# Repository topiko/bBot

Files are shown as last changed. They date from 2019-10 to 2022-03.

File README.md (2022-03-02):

### Robert is a much cabable balancing robot!

Check the notes of how to make it balance in control.pdf (also the Kalman filter math) and in practice in Raspberry/balance_run.py

[Video link](https://www.youtube.com/watch?v=8lWUVSnFbXg)

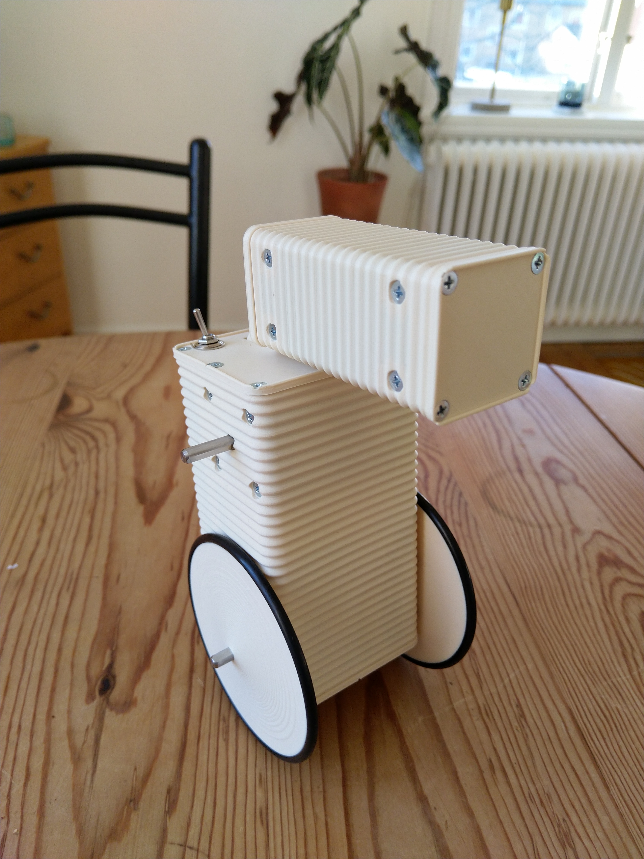
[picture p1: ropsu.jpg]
Robert (https://www.youtube.com/watch?v=8lWUVSnFbXg)


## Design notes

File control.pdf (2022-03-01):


Figure 1: Ropsu looks good and has wheels and head

# How to make Ropsu Balance

Topsu | 20/05/2020

# 1 Overview

You need to keep Ropsu upright. Ropsu is very unstable!

You can only acces the wheel angular velocity, under no slip this means velocity of Ropsus

hip.

Lagrange of Ropsu reads (See. A):

## L = −F x(t) + J

2

d

## dtθ(t)

2

## − Lcmgm cos (θ(t)) + Lcmm cos (θ(t)) d dtθ(t)

d

## dtx(t) + m

2

d

## dtx(t)

2

(1)

From which we yield Eqs. of motion:

## F − Lcmm sin (θ(t))

d

## dtθ(t)

2

## + Lcmm cos (θ(t)) d

2

## dt²

## θ(t) + m

d

2

## dt²

x(t) = 0 | (2)

J

d

2

## dt²

## θ(t) − Lcmgm sin (θ(t)) + Lcmm cos (θ(t)) d

2

## dt²

x(t) = 0 | (3)

Using 3 we get:

d

2

## dt²

θ =

## Lcmm

J

## g sin (θ(t)) − cos (θ(t)) d

2

## dt²

x(t)

(4)

a = −

J

d

2
dt² θ(t)
Lcmm cos (θ(t)) + g tan (θ(t)) | (5)

Equipped with Eq. 4 we can see how to apply a in each situation θ to achieve given d

2
dt² θ. Control

is then based in deciding desired d

2
dt² θ using Eq. 4 get a.

# 2 Model Fit

We always record a, θ, d

2
dt² θ so using Eq. 4 we can fit a model and obtain the factor Lcmm J

. This

is further fed to the Kalman filter.

# 3 Control

We use PID to get:
d

2

## dt²

## θ = P∆θ + I

Z

## ∆θdt + D

d
dt∆θ, | (6)
where ∆θ is the difference from targeted θ. | Note that using I = 0 this is damped harmonic

oscillator.

# 3.1 Issue

We get particularly crappy and noisy values for the d

2
dt² θ (see Fig. 2). I suppose also the values

d
dtθ are messed and hence the obtained values a become also very noisy. This leads to all sorts

of issues. <++>

# 4 Hardware

We use RaspberryPi Zero and an arduino due communicating via serila connection. Arduino

takes care of readin values from IMU (inertial measurement unit) and controlling the wheels/-

head/hands (as of now only wheels and head). We use stepper motors to have precise control

over the position. Raspberry is used to take care of all control logic since I am not very com-

fortable with c++. Moreover I can easily ssh into the Raspberry and do the development without

need to flash the program into arduino etc..

# A Lagrange

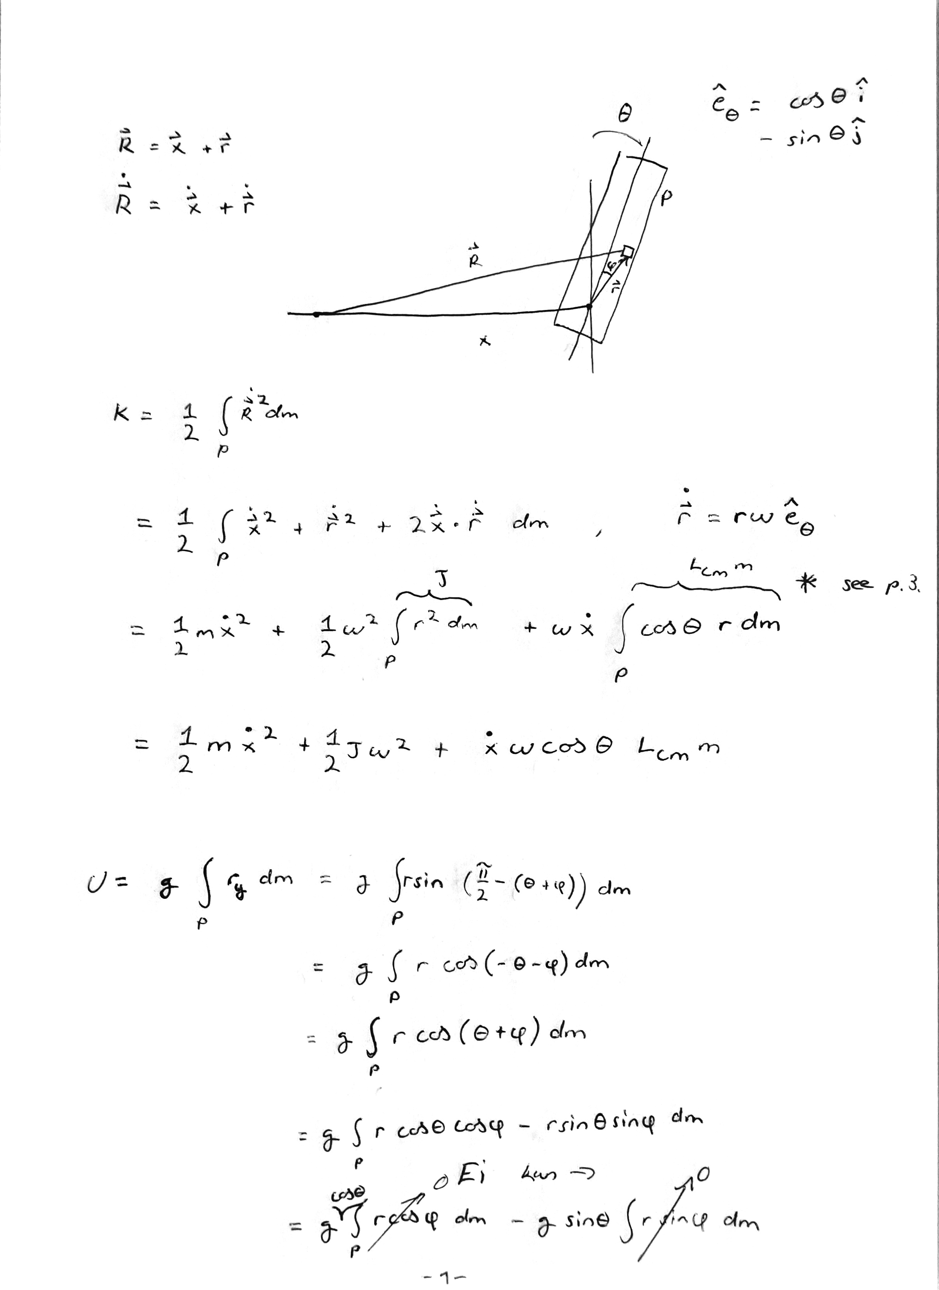
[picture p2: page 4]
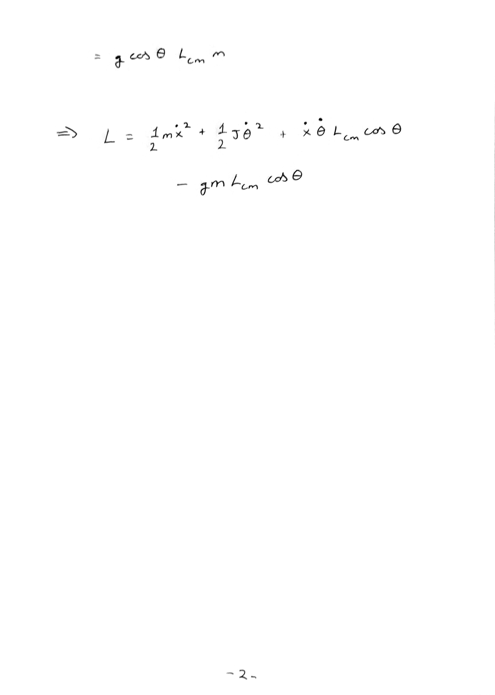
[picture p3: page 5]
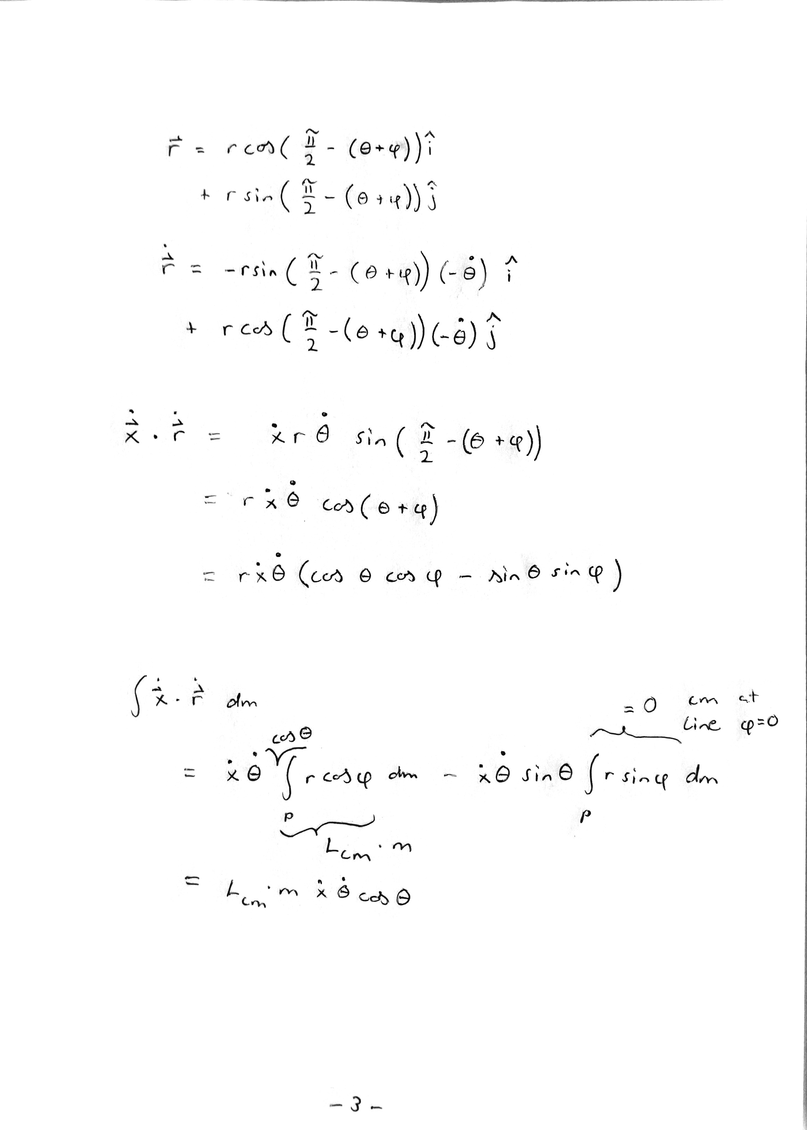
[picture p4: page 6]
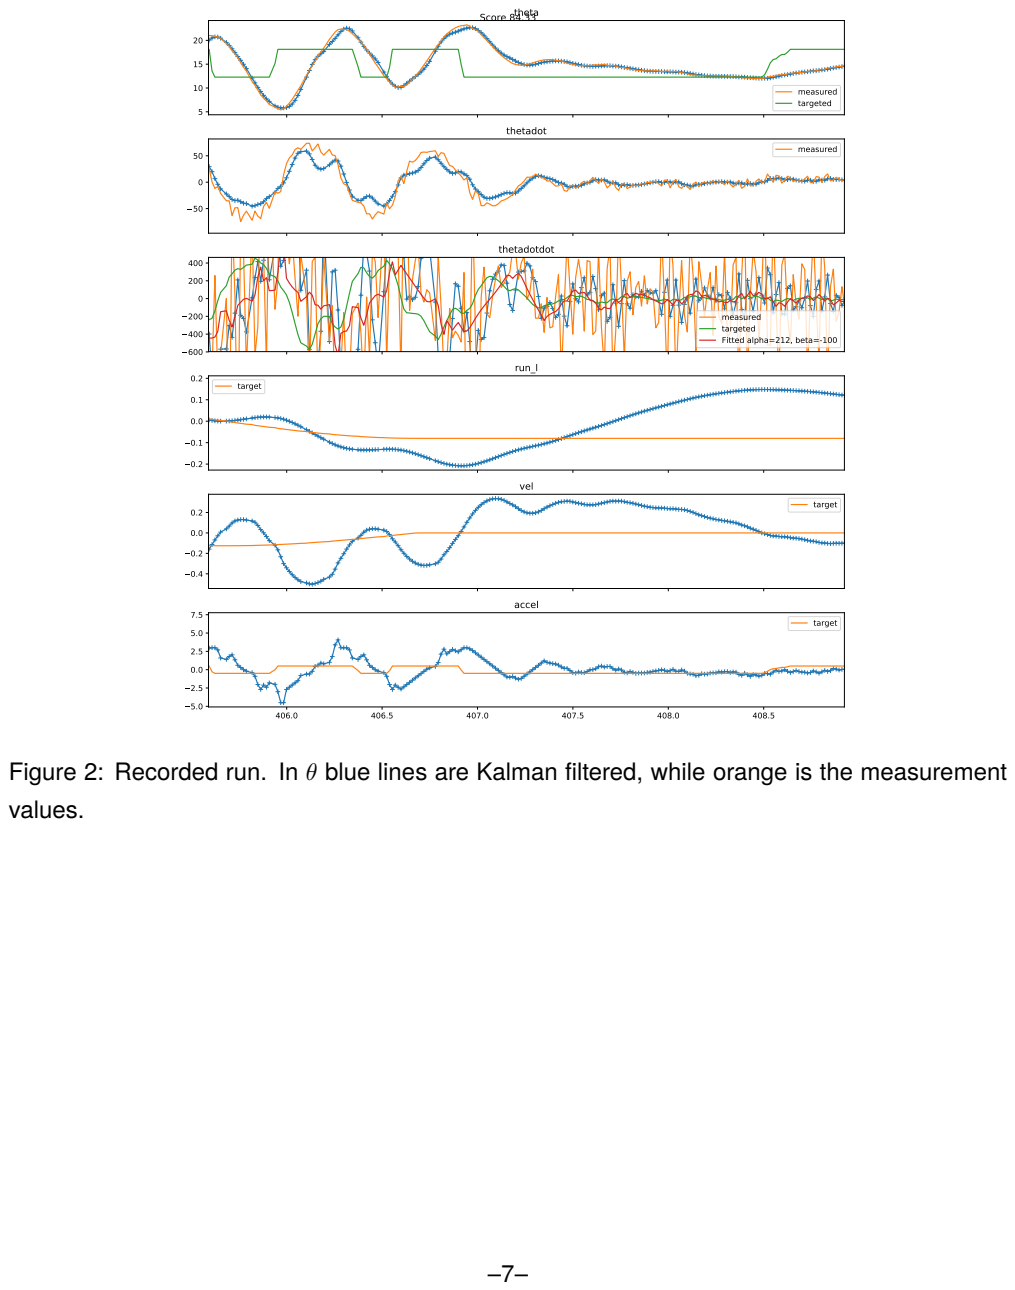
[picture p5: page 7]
theta; measured targeted; thetadot; measured; thetadotdot; run_l; target; vel; accel; Score 84.33; values.

measured
targeted
Fitted alpha=212, beta=-100

Figure 2: Recorded run. In θ blue lines are Kalman filtered, while orange is the measurement

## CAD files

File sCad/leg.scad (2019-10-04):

include <design.scad>;
use <nema14.scad>;
use <wigleUnit.scad>;
use <wheel.scad>;


module noLeg(wx, wy, r_corner, sc, sc2, mid, A_out, ni, t, t_motor_mount, wall_t, axle_x, bolt_sink, motors, a){

    
    axle_h = t + nema14_x/2;
    
    // LEG:    
    module motor_and_wheel_(){
        // MOTOR MOUNTS
        translate([axle_x, -nema14_z + wy/2 - t_motor_mount + A_out, axle_h])   rotate([-90,0,0])
        union(){
        if (motors==1){
            union(){
                nema14(3*a);
                nema_bolts(t_motor_mount - bolt_sink, nema_bolt_d/2, 3*a);
                translate([0,0,nema14_z + 6]) wheel();
            }
        }
        // motor mount:
        else if (motors==2) {
             nema14_mount(t_motor_mount, 3*a);
        }
        
        // bolts
        else if (motors==3) {
            echo(a);
             nema_bolts(t_motor_mount - bolt_sink, nema_bolt_d/2, 3*a);
        }
        
        }
    }
    
    
    
    motor_and_wheel_();
        
}



//noLeg(wx, wy, r_corner, sc, sc2, mid, A_out, ni, t, t_motor_mount, wall_t, axle_x, t_motor_mount - 2, 1, a);
//noLeg(wx, wy, r_corner, sc, sc2, mid, A_out, ni, t, t_motor_mount, wall_t, axle_x, t_motor_mount - bolt_wall_t, 1, a);
noLeg(wx, wy, r_corner, sc, sc2, mid, A_out, ni, t, t_motor_mount, wall_t, axle_x, t_motor_mount - bolt_wall_t, 1, a);

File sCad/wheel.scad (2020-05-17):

include <design.scad>;

Pi = 3.141592653589793;

r_tube = 2;
t_rim = 3.5;
D_wheel = 91;
dist_tube = sqrt(pow(r_tube,2) - pow(t_rim/2,2));
echo(D_wheel);
echo(dist_tube);
R = D_wheel/2 - dist_tube - r_tube;
wRim = 20;
maxPhi = 270;
wall_t = 10;
t_hub = 14;

a = 50;
nema_axle_h = 14;
nema_axle_r = 2.54;
r0 = nema_axle_r - .5;

D = (R - wRim + wall_t)/r0;

n_spokes = 8;

function spiral(r0, D, x, phi) = (r0*exp(ln(D)/maxPhi*phi)-x)*[cos(phi),sin(phi)];
function reverse(list) = [for (i=[len(list)-1:-1:0]) list[i]];
function spiral_points(r0, D, maxPhi, x, a) = [for (i=[0:1:a]) spiral(r0, D, x, i/a*maxPhi)]; 

function spiral_polygon_points(r0, D, maxPhi, wall_t, a) = concat(spiral_points(r0, D, maxPhi, 0, a), reverse(spiral_points(r0, D, maxPhi, wall_t, a)));

function poly2(a,b,c, x) = [x, a*pow(x, 2) + b*x + c];


module spokes(){
    for (i=[0:1:n_spokes]){
        rotate([0,0,360/n_spokes*i]) polygon(points = spiral_polygon_points(r0, D, maxPhi, wall_t, a));    
    }
}

module nema_axle_(){
    difference(){
            cylinder(r = nema_axle_r, h = nema_axle_h, $fn = a);
            translate([-50, nema_axle_r - .5,0])cube(100);
    }
}

module hub(){
    circle(r=r0, $fn = a);
}

module rim(){
    difference() {
        circle(r=R, $fn = a);
        circle(r=R-wRim, $fn = 2*a);
    }
}


module wheel(){
    
    /*
    module spokes_rims_(){
        linear_extrude(height = max(t_hub, t_rim)){
            hub();
            rim();
            spokes();
        }
    }
    */
    
    module side_profile_(){
        denom = pow(R, 2) - 2*R*r0 + pow(r0, 2);
        a_ = (t_hub - t_rim)/denom;
        b_ = 2*R*(t_rim - t_hub)/denom;
        c_ = (pow(R, 2)*t_hub - r0*t_rim*(2*R - r0))/denom;
        p = concat([[r0,t_hub+1]], [for (x=[r0:R/a:R]) poly2(a_,b_,c_, x)], [[R+1, t_rim], [R+1, t_hub+1]]);
        rotate_extrude($fn = 2*a) polygon(points = p);
    }
    
    color("DarkGray")
    
    difference(){
        //spokes_rims_();
        cylinder(r = R, h = t_hub, $fs = dt/2, $fa = dTHETA);
        side_profile_();
        // Tyre
        rotate_extrude($fs = dt/2, $fa = dTHETA) translate([R + dist_tube,t_rim/2]) circle(r=r_tube, $fs = dt/2, $fa = dTHETA);
        // motor axle
        nema_axle_();
        // Fixing bolt
        fix_bolt();
    }
    
    //cylinder(r = 7, h = t_hub, $fa = dTHETA);
    module fix_bolt(){
        bolt_l = 6;
        H = t_hub/3*2; 
        translate([0, nema_axle_r + bolt_l - .5, H]) rotate([90,0,180]){
        bolt_new(bolt_l, 1.4, 20);
        translate([0,0,1.5]) cylinder(r=1.6*2, h = 20, $fs = dt/2, $fa=dTHETA);
            }
    }
    
    
    //color("Black") rotate_extrude($fs = dt/2, $fa = dTHETA) translate([R + dist_tube,t_rim/2]) circle(r=r_tube, $fs = dt/2, $fa = dTHETA);
    
    
    
}

/*
intersection(){
    wheel();
    cylinder(r=7, h = t_hub);
}*/
    
wheel();

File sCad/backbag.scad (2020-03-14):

include <design.scad>;
use <wigleUnit.scad>;
use <utils.scad>;
use <elMount.scad>;
use <covers.scad>;
use <rims.scad>;
use <neck.scad>;


module backbag_top_cover(move){
    
    //_backbag_bottom,
    w_rim_top = wall_t;
    r_cables = 1;
    width_cable_slot = 20;
    difference(){
    topCover(wx_backbag, wy_backbag, r_corner_backbag, sc_backbag, sc2_backbag, mid_backbag, A_out, w_rim_top,  ni_backbag, t, heights_backbag, thickness_bottom, bottom_rim_w, wall_t, move, a);
        translate([wx_backbag/2 - r_cables  - bottom_rim_w, -bottom_rim_w, 0]){
            hull(){
            translate([0, wy_backbag/2 - r_cables,0]) cylinder(r = r_cables, h = 100000, $fn = 4*a);
            translate([0, wy_backbag/2 - r_cables - width_cable_slot,0]) cylinder(r = r_cables, h = 100000, $fn = 4*a);
            }
        }
    }

}

//w_rim_low = 2;
backbag_bottom_rim_w = 1;
w_rim_backbag_bottom = 1;

module backbag_bottom_cover(){
    
    echo(backbag_bottom_rim_w);
    bottomCover(wx_backbag, wy_backbag, r_corner_backbag, sc_backbag, sc2_backbag, mid_backbag, A_out, w_rim_backbag_bottom, ni_backbag, t, heights_backbag, thickness_bottom, bottom_rim_w, wall_t, 1, a);
    
}

module backbag_old(){
    
    H_backbag = ni_backbag*t;
    
    module moved_converter_mount(mode){
        translate([-wx_backbag/2 - A_out, 54/2 - wy_backbag/2 + 3, t]) rotate([90, 0,90]) converter_mount(el_mount_h, bolt_sink, mode, 3*a);
    }
    
    switch_move_y = 2*switch_d;
    module moved_switch_mount(mode){
        translate([-wx_backbag/2 - A_out, wy_backbag/2 - switch_move_y, switch_d/2 + t/2]) rotate([90, 0,90]) hole_mount(mode, switch_d/2, r_out = 5);
    }
    
    module moved_led_mount(mode){
        translate([-wx_backbag/2 - A_out, wy_backbag/2 - switch_move_y, switch_d/2 + 2.5*t-1]) rotate([90, 0,90]) hole_mount(mode, 1.5, r_out = 3);
    }
    
    h_bat_sup = ni_backbag*t*.6;
    bat_sup_x = -wx_backbag/2 + (wx_backbag - bat_z) - 3;
    module backbag_shell_(){
        difference(){
        union() {
            shell(wall_t, 1, 1, .5, t, wx_backbag, wy_backbag, r_corner_backbag, ni_backbag, A_in, A_out, a);
            upRim(wx_backbag, wy_backbag, r_corner_backbag, sc_backbag, sc2_backbag, mid_backbag, wall_t, ni_backbag, A_out, t, heights_backbag, 0, a);
            lowerRim(wx_backbag, wy_backbag, r_corner_backbag, sc_backbag, sc2_backbag, mid_backbag, wall_t, ni_backbag, A_out, t, 2, 0, a);
            
        // Converter mount
        intersection(){
            moved_converter_mount(0);
            shell(el_mount_h, 1, 1, .5, t, wx_backbag, wy_backbag, r_corner_backbag, ni_backbag, A_in, A_out, a);
        }
        // battery support
        intersection(){
            translate([bat_sup_x,0,h_bat_sup/2]) cube([.33*4, wy_backbag, h_bat_sup], center = true);
            shell(10, 1, 1, .5, t, wx_backbag, wy_backbag, r_corner_backbag, ni_backbag, A_in, A_out, a);
        }
        translate([bat_sup_x,0,h_bat_sup/2]) cube([.33*4, wy_backbag, h_bat_sup], center = true);
        // switch mount
        moved_switch_mount(0);
        
        // led mount
        moved_led_mount(0);
        }
        moved_converter_mount(2);
        moved_switch_mount(2);
        moved_led_mount(2);
    }
        
        
        
        
        
    }
    
    // backbag SHELL
    //rotate([0,-90,0]){
    color("DarkSlateGray")backbag_shell_();
    translate([0,0,.01])backbag_bottom_cover();    
    //}
    
    
}

module backbag(){
    
    H_backbag = ni_backbag*t;
    
    module moved_converter_mount(mode){
        translate([-wx_backbag/2 - A_out, 54/2 - wy_backbag/2 + 3, t]) rotate([90, 0,90]) converter_mount(el_mount_h, bolt_sink, mode, 3*a);
    }
    
    
    module backbag_shell_(){
    
        union() {
            shell(wall_t, 1, 1, .5, t, wx_backbag, wy_backbag, r_corner_backbag, ni_backbag, A_in, A_out, a);
            
            
        
        }
        //moved_converter_mount(2);
        //moved_switch_mount(2);
        //moved_led_mount(2);
        R = 8;
        dx = 1.6;
        intersection(){
            shell(dx + wall_t, 1, 1, .5, t, wx_backbag + 2*dx, wy_backbag + 2*dx, r_corner_backbag, 4, A_in, A_out, a);
            hull(){
                rotate([0,50,0]){
                    
                translate([0, -2*R, 0]) cylinder(r = R, h = wy_backbag, $fn = 5*a);
                translate([0, 2*R, 0])cylinder(r = R, h = wy_backbag, $fn = 5*a);
                }
            }
        }
        
        upRim(wx_backbag, wy_backbag, r_corner_backbag, sc_backbag, sc2_backbag, mid_backbag, wall_t, ni_backbag, A_out, t, heights_backbag, 0, a);
        lowerRim(wx_backbag, wy_backbag, r_corner_backbag, sc_backbag, sc2_backbag, mid_backbag, wall_t, ni_backbag, A_out, t, 2, 0, a);
        
        
    }
    
    // backbag SHELL
    //rotate([0,-90,0]){
    color("DarkSlateGray")backbag_shell_();
    translate([0,0,.01])backbag_bottom_cover();    
    //}
    
    
}


module display_backbag(dx, H){
    
    /*
    translate([-wx/2 - thickness_bottom - A_out - dx, 0, H])
    rotate([0,-90,0])rotate([0,0,90]){
        backbag();
        backbag_top_cover(1);
    }*/
    // translate([+wx/2 + thickness_bottom + A_out + dx + wx_backbag/2, 0, H])
    translate([-wx/2 - thickness_bottom - A_out - dx - wx_backbag/2, 0, H])
    {
        backbag();
        backbag_top_cover(1);
    }
}


//display_backbag(1, 120);
a = 10;
backbag();
//backbag_bottom_cover();
//backbag_top_cover(1);

/*
backbag();
top = 0;


intersection() {
    translate([0,0,500.001])cube(1000, center = true);
    if (top == 0) backbag_bottom_cover();
    else if (top == 1) backbag_top_cover(0);
}


intersection() {
    translate([0,0,-500 - .001])cube(1000, center = true);
    if (top == 0) backbag_bottom_cover();
    else if (top == 1) backbag_top_cover(0);
}
*/


//backbag_bottom_cover();

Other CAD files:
sCad/batContainer.scad
sCad/body.scad
sCad/build.scad
sCad/build.scad.scad
sCad/covers.scad
sCad/design.scad
sCad/due_nut.scad
sCad/elMount.scad
sCad/hand.scad
sCad/head.scad
sCad/neck.scad
sCad/nema14.scad
sCad/rims.scad
sCad/spring.scad
sCad/tool.scad
sCad/utils.scad
sCad/wigleUnit.scad

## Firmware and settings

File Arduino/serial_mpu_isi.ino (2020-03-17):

// I2C device class (I2Cdev) demonstration Arduino sketch for MPU6050 class using DMP (MotionApps v2.0)
// 6/21/2012 by Jeff Rowberg <jeff@rowberg.net>
// Updates should (hopefully) always be available at https://github.com/jrowberg/i2cdevlib
//
// Changelog:
//      2013-05-08 - added seamless Fastwire support
//                 - added note about gyro calibration
//      2012-06-21 - added note about Arduino 1.0.1 + Leonardo compatibility error
//      2012-06-20 - improved FIFO overflow handling and simplified read process
//      2012-06-19 - completely rearranged DMP initialization code and simplification
//      2012-06-13 - pull gyro and accel data from FIFO packet instead of reading directly
//      2012-06-09 - fix broken FIFO read sequence and change interrupt detection to RISING
//      2012-06-05 - add gravity-compensated initial reference frame acceleration output
//                 - add 3D math helper file to DMP6 example sketch
//                 - add Euler output and Yaw/Pitch/Roll output formats
//      2012-06-04 - remove accel offset clearing for better results (thanks Sungon Lee)
//      2012-06-01 - fixed gyro sensitivity to be 2000 deg/sec instead of 250
//      2012-05-30 - basic DMP initialization working

/* ============================================
  I2Cdev device library code is placed under the MIT license
  Copyright (c) 2012 Jeff Rowberg

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
  THE SOFTWARE IS PROVIDED "AS IS", WITHOUT WARRANTY OF ANY KIND, EXPRESS OR
  IMPLIED, INCLUDING BUT NOT LIMITED TO THE WARRANTIES OF MERCHANTABILITY,
  FITNESS FOR A PARTICULAR PURPOSE AND NONINFRINGEMENT. IN NO EVENT SHALL THE
  AUTHORS OR COPYRIGHT HOLDERS BE LIABLE FOR ANY CLAIM, DAMAGES OR OTHER
  LIABILITY, WHETHER IN AN ACTION OF CONTRACT, TORT OR OTHERWISE, ARISING FROM,
  OUT OF OR IN CONNECTION WITH THE SOFTWARE OR THE USE OR OTHER DEALINGS IN
  THE SOFTWARE.
  ===============================================
*/

// I2Cdev and MPU6050 must be installed as libraries, or else the .cpp/.h files
// for both classes must be in the include path of your project
#include "I2Cdev.h"

#include "MPU6050_6Axis_MotionApps20.h"

// stepper library
#include <AccelStepper.h>


// use servos:
#include <Servo.h>


// Arduino Wire library is required if I2Cdev I2CDEV_ARDUINO_WIRE implementation
// is used in I2Cdev.h
#if I2CDEV_IMPLEMENTATION == I2CDEV_ARDUINO_WIRE
#include "Wire.h"
#endif

// class default I2C address is 0x68
// specific I2C addresses may be passed as a parameter here
// AD0 low = 0x68 (default for SparkFun breakout and InvenSense evaluation board)
// AD0 high = 0x69
MPU6050 mpu;


/* =========================================================================
   NOTE: In addition to connection 3.3v, GND, SDA, and SCL, this sketch
   depends on the MPU-6050's INT pin being connected to the Arduino's
   external interrupt #0 pin. On the Arduino Uno and Mega 2560, this is
   digital I/O pin 2.
   ========================================================================= */


// MPU control/status vars
bool dmpReady = false;  // set true if DMP init was successful
uint8_t mpuIntStatus;   // holds actual interrupt status byte from MPU
uint8_t devStatus;      // return status after each device operation (0 = success, !0 = error)
uint16_t packetSize;    // expected DMP packet size (default is 42 bytes)
uint16_t fifoCount;     // count of all bytes currently in FIFO
uint8_t fifoBuffer[64]; // FIFO storage buffer


// command given by rpi
unsigned char command[3] = {0, 0, 0};
int pitchInt;
volatile boolean inSer = false;
unsigned long time_read_imu = 0;
unsigned long prev_imu_read_time = 0;
unsigned long dt = 0;
int comIdx = 0;
int n1 = 0;
int n2 = 0;
int n3 = 0;
boolean usb = false;

// Stepper motor variables:
// leg pins:

#define dirPin_Lleg 50
#define stepPin_Lleg 48
#define dirPin_Rleg 42
#define stepPin_Rleg 40
// hand pins:
#define dirPin_Rhand 34
#define stepPin_Rhand 32
#define dirPin_Lhand 26
#define stepPin_Lhand 24

// This tels that we have a driver for the stepper:
#define motorInterfaceType 1

// Max speed and acc:
#define leg_step_multip 2
#define maxStepperSpeed 1024*leg_step_multip //2048
#define maxStepperAcc 1024*2*leg_step_multip

AccelStepper lLeg = AccelStepper(motorInterfaceType, stepPin_Lleg, dirPin_Lleg);
AccelStepper rLeg = AccelStepper(motorInterfaceType, stepPin_Rleg, dirPin_Rleg);
AccelStepper lHand = AccelStepper(motorInterfaceType, stepPin_Lhand, dirPin_Lhand);
AccelStepper rHand = AccelStepper(motorInterfaceType, stepPin_Rhand, dirPin_Rhand);

// stepper setup pins:
#define enablePin 52
#define stepModeCOM0Hand 38
#define stepModeCOM1Hand 36
#define stepModeCOM0Leg 44
#define stepModeCOM1Leg 46
#define enablePinHands 28
#define enablePinLegs 30


int lLeg_speed = 0;
int rLeg_speed = 0;
int lHand_speed = 0;
int rHand_speed = 0;

//MultiStepper steppers; // upt to 10 steppers we can use MultiStepper

// Head tilt servo:
# define servoPin 12
Servo headServo;  // create servo object to control a servo

// orientation/motion vars
Quaternion q;           // [w, x, y, z]         quaternion container
VectorInt16 aa;         // [x, y, z]            accel sensor measurements
VectorInt16 aaReal;     // [x, y, z]            gravity-free accel sensor measurements
VectorInt16 aaWorld;    // [x, y, z]            world-frame accel sensor measurements
VectorFloat gravity;    // [x, y, z]            gravity vector
float euler[3];         // [psi, theta, phi]    Euler angle container
float ypr[3];           // [yaw, pitch, roll]   yaw/pitch/roll container and gravity vector


// ================================================================
// ===               INTERRUPT DETECTION ROUTINE                ===
// ================================================================

volatile bool mpuInterrupt = false;     // indicates whether MPU interrupt pin has gone high

void dmpDataReady() {
  mpuInterrupt = true;
}

// RPI serial interrupt:
// =========================
void serialEvent3() {
  inSer = true;
}
// =========================

// ================================================================
// ===                      INITIAL SETUP                       ===
// ================================================================

void setup() {

  // Setup stepper pins:
  pinMode(stepModeCOM0Leg, OUTPUT);
  pinMode(stepModeCOM1Leg, OUTPUT);
  pinMode(stepModeCOM0Hand, OUTPUT);
  pinMode(stepModeCOM1Hand, OUTPUT);
  pinMode(enablePin, OUTPUT);
  pinMode(enablePinHands, OUTPUT);
  pinMode(enablePinLegs, OUTPUT);

  // pulls drivers from sleep mode:
  digitalWrite(enablePin, HIGH);

  // disables steppers
  digitalWrite(enablePinLegs, HIGH);
  digitalWrite(enablePinHands, HIGH);

  // 1/2 step
  digitalWrite(stepModeCOM0Leg, HIGH); 
  digitalWrite(stepModeCOM1Leg, LOW);

  // 1/8 microstepping
  digitalWrite(stepModeCOM0Hand, HIGH);
  digitalWrite(stepModeCOM1Hand, HIGH);


  // join I2C bus (I2Cdev library doesn't do this automatically)
#if I2CDEV_IMPLEMENTATION == I2CDEV_ARDUINO_WIRE
  Wire.begin();
  //TWBR = 24; // 400kHz I2C clock (200kHz if CPU is 8MHz)
#elif I2CDEV_IMPLEMENTATION == I2CDEV_BUILTIN_FASTWIRE
  Fastwire::setup(400, true);
#endif

  // initialize serial communication
  // (115200 chosen because it is required for Teapot Demo output, but it's
  // really up to you depending on your project)
  if (usb) Serial.begin(115200);


  //while (!Serial); // wait for Leonardo enumeration, others continue immediately

  // NOTE: 8MHz or slower host processors, like the Teensy @ 3.3v or Ardunio
  // Pro Mini running at 3.3v, cannot handle this baud rate reliably due to
  // the baud timing being too misaligned with processor ticks. You must use
  // 38400 or slower in these cases, or use some kind of external separate
  // crystal solution for the UART timer.

  // initialize device
  if (usb) Serial.println(F("Initializing I2C devices..."));
  mpu.initialize();

  // verify connection
  if (usb) Serial.println(F("Testing device connections..."));
  if (usb) Serial.println(mpu.testConnection() ? F("MPU6050 connection successful") : F("MPU6050 connection failed"));
  else mpu.testConnection();

  // wait for ready
  //Serial.println(F("\nSend any character to begin DMP programming and demo: "));
  //while (Serial.available() && Serial.read()); // empty buffer
  //while (!Serial.available());                 // wait for data
  //while (Serial.available() && Serial.read()); // empty buffer again

  // load and configure the DMP
  if (usb) Serial.println(F("Initializing DMP..."));
  devStatus = mpu.dmpInitialize();

  // supply your own gyro offsets here, scaled for min sensitivity
  /*
    mpu.setXGyroOffset(220);
    mpu.setYGyroOffset(76);
    mpu.setZGyroOffset(-85);
    mpu.setZAccelOffset(1788); // 1688 factory default for my test chip
  */

  // make sure it worked (returns 0 if so)
  if (devStatus == 0) {
    // turn on the DMP, now that it's ready
    if (usb) Serial.println(F("Enabling DMP..."));
    mpu.setDMPEnabled(true);

    // enable Arduino interrupt detection
    if (usb) Serial.println(F("Enabling interrupt detection (Arduino external interrupt 0)..."));

    attachInterrupt(23, dmpDataReady, RISING);

    mpuIntStatus = mpu.getIntStatus();

    // set our DMP Ready flag so the main loop() function knows it's okay to use it
    if (usb) Serial.println(F("DMP ready! Waiting for first interrupt..."));
    dmpReady = true;

    // get expected DMP packet size for later comparison
    packetSize = mpu.dmpGetFIFOPacketSize();
  } else {
    // ERROR!
    // 1 = initial memory load failed
    // 2 = DMP configuration updates failed
    // (if it's going to break, usually the code will be 1)
    if (usb) Serial.print(F("DMP Initialization failed (code "));
    if (usb) Serial.print(devStatus);
    if (usb) Serial.println(F(")"));
  }

  // Stepper configurations:
  // speeds:
  lLeg.setMaxSpeed(maxStepperSpeed);
  rLeg.setMaxSpeed(maxStepperSpeed);
  lHand.setMaxSpeed(maxStepperSpeed);
  rHand.setMaxSpeed(maxStepperSpeed);
  // acccels:
  lLeg.setAcceleration(maxStepperAcc);
  rLeg.setAcceleration(maxStepperAcc);
  lHand.setAcceleration(maxStepperAcc);
  rHand.setAcceleration(maxStepperAcc);

  //servo:
  headServo.attach(servoPin);
  headServo.write(90);

  // Signal if dmp initialize was succesfull by nodding head:
  if (!dmpReady) {
    for (int i = 0; i < 200; i++) {
      if (i % 2 == 0) headServo.write(70);
      else if (i % 2 == 1) headServo.write(110);
      delay(10);
    }
  }
  else {
    for (int i = 0; i < 10; i++) {
      if (i % 2 == 0) headServo.write(90);
      else if (i % 2 == 1) headServo.write(120);
      delay(1000);
    }
  }

  // Wait for raspberry to start
  delay(1000 * 30);

  // RPI serial
  Serial3.begin(115200);

  // Nod head to say hello
  for (int i = 0; i < 10; i++) {
    if (i % 2 == 0) headServo.write(120);
    else if (i % 2 == 1) headServo.write(90);
    delay(100);
  }

  headServo.write(120);

}



// ================================================================
// ===                    MAIN PROGRAM LOOP                     ===
// ================================================================
void loop() {
  // if programming failed, don't try to do anything
  if (!dmpReady) return;

  // wait for MPU interrupt or extra packet(s) available
  while (!mpuInterrupt && fifoCount < packetSize) {

    // run the motors
    lLeg.setSpeed(lLeg_speed);
    rLeg.setSpeed(rLeg_speed);
    lHand.setSpeed(lHand_speed);
    rHand.setSpeed(rHand_speed);

    lHand.run();
    rHand.run();
    lLeg.run();
    rLeg.run();

    if (inSer) {
      inSer = false;

      // only compute if requested:
      mpu.dmpGetQuaternion(&q, fifoBuffer);
      mpu.dmpGetGravity(&gravity, &q);
      mpu.dmpGetYawPitchRoll(ypr, &q, &gravity);

      comIdx = 0;
      while (comIdx < 3) {
        while (Serial3.available() > 0) {
          command[comIdx] = Serial3.read();
          comIdx++;
        }
      }

      n1 = command[0] >> 6;
      n2 = (((command[0] & 63) << 5) | (command[1] >> 3)) - 1024;
      n3 = ((command[1] & 7) << 8 | command[2]) - 1024;

      pitchInt = (int)(20860 * ypr[1]); // * 180/M_PI)
      
      //dt = time_read_imu - prev_imu_read_time;
      //prev_imu_read_time = time_read_imu;

      Serial3.write(pitchInt >> 8);
      Serial3.write(pitchInt & 0xff);
      //Serial3.write(dt >> 8);
      //Serial3.write(dt & 0xff);

      Serial3.write(time_read_imu >> 24);
      Serial3.write(time_read_imu >> 16);
      Serial3.write(time_read_imu >> 8);
      Serial3.write(time_read_imu & 0xff);

      
      if (usb) {
        Serial.print("Pitch int: ");
        Serial.print(pitchInt);
        Serial.print("\t");
        Serial.print("FiFO count ");
        Serial.print(mpu.getFIFOCount());
        Serial.print("\t");
        Serial.print("pitch\t");
        Serial.print(ypr[1] * 180 / M_PI); //ypr[1] * 180/M_PI);
        Serial.print("\tcommand\t");
        Serial.print(n1);
        Serial.print("\t");
        Serial.print(n2);
        Serial.print("\t");
        Serial.println(n3);
      }

      if (n1 == 0) {
        lLeg_speed = leg_step_multip * n2;
        rLeg_speed = leg_step_multip * n3;
        lLeg.moveTo(lLeg.currentPosition() + leg_step_multip * n2);
        rLeg.moveTo(rLeg.currentPosition() + leg_step_multip * n3);
      }
      else if (n1 == 1) {
        lHand_speed = n2;
        lHand.moveTo(lHand.currentPosition() + n3);
      }
      else if (n1 == 2) {
        rHand_speed = n2;
        rHand.moveTo(rHand.currentPosition() + n3);
      }
      else if (n1 == 3) {
        if (n2 == 0) {
          // disable motors
          digitalWrite(enablePinLegs, HIGH);
          digitalWrite(enablePinHands, HIGH);
        }
        else if (n2 == 1) {
          // enable Legs
          digitalWrite(enablePinLegs, LOW);
        }
        else if (n2 == 2) {
          // enable hannds
          digitalWrite(enablePinHands, LOW);
        }
        else if (n2 == 3) {
          // note 0 <= n2 < 256:
          headServo.write(n3);
        }
      }
    }
  }


  // reset interrupt flag and get INT_STATUS byte
  mpuInterrupt = false;
  mpuIntStatus = mpu.getIntStatus();

  // get current FIFO count
  fifoCount = mpu.getFIFOCount();

  // check for overflow (this should never happen unless our code is too inefficient)
  if ((mpuIntStatus & 0x10) || fifoCount == 1024) {
    // reset so we can continue cleanly
    mpu.resetFIFO();
    if (usb) {
      Serial.println(F("FIFO overflow!"));
    }
    else {
      Serial3.write("0");
      Serial3.write("1");
    }
    //Serial3.println(F("FIFO overflow!"));

    // otherwise, check for DMP data ready interrupt (this should happen frequently)
  }
  else if (mpuIntStatus & 0x02) {
    // wait for correct available data length, should be a VERY short wait
    while (fifoCount < packetSize) fifoCount = mpu.getFIFOCount();

    // read a packet from FIFO
    mpu.getFIFOBytes(fifoBuffer, packetSize);

    time_read_imu = micros();

    // track FIFO count here in case there is > 1 packet available
    // (this lets us immediately read more without waiting for an interrupt)
    fifoCount -= packetSize;
  }

}

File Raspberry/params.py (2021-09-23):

"""
Various physical parameters
"""
import numpy as np

UPRIGHT_THETA = 15.5 #15.2 Usuakky
STEPS_PER_REV = 1600 #1600 # used to be 400 This would then be 200*8...
ARDUINO_STEP_MULTIP = 8 #
WHEEL_DIA = .092
RAIL_W = .078
PI = 3.14159267

DT = .016

AMPLITUDE = .00 ##12 #12
INIT_THETA_DEV = 1
PHIDOT = 90

# Method for optimizing the ctrl parameters: ('L-BFGS-B', 'brute')
OPM_METHOD = 'diff_evo' #'L-BFGS-B' #'diff_evo' #'L-BFGS-B' #'brute'

# maximum targeted accel:
MAX_V = 1.0
MAX_A = 2.0
MAX_A_CTRL = 30
MAX_V_CTRL = (1024 * ARDUINO_STEP_MULTIP / STEPS_PER_REV) * PI*WHEEL_DIA

MAX_JERK = 500 #20

# Dyn params
LCM = 0.05 # Distance of center of mass from wheel axle
MASS = 1.0 # mass of the robot
J = 0.14**2 #MASS * LCM**2  # moment of inertia

ALPHA = 4.7 # (MASS * LCM / J) #40 #736
print('ALPHA = {:.2f}'.format(ALPHA))

ALPHA_SIMUL = ALPHA # - 30

GRAVITY_ACCEL = 9.81

# Uncertainty in theta measurement
SIGMA_THETA = .0015**2 # .015**2
SIGMA_THETADOTDOT = .002 # 0.15 is a good value
KL_USE_INPUT = True #False #True #False

SIMUL_LOOP_TIME = 22.5
OPM_LOOP_TIME = 7 #22.5
RUN_LOOP_TIME = 120

KAPPA_D_THETA = None #1/2
REMOTE_DX = 0.005
try:
    CTRL_PARAMS_DICT = np.load('ctrl_params.npy', allow_pickle=True).item()
except FileNotFoundError:
    CTRL_PARAMS_DICT = {'P_pos':5,
                        'D_pos':2,
                        'I_pos':.0,
                        'P_theta':100, #150 350 150
                        'D_theta':20, #30 55, 55, # 20
                        'I_theta':0, #1.5,
                        'accel_mltp':1.0}

#                        'damp_theta':1.0,
#                        'omega_theta':1/(.015*2*np.pi)}
COLLECT_DATA = ['times', 'theta',
                'thetadot', 'thetadotdot',
                'theta_measured', 'thetadot_measured',
                'thetadotdot_measured',
                'target_theta', 'target_thetadot',
                'target_thetadotdot',
                'target_x', 'target_y', 'target_v',
                'target_l',
                'run_l',
                'v', 'a', 'x', 'y', 'phi', 'a1', 'a2',
                'target_a'] #, 'theta_predict']

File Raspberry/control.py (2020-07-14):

"""
This is the control packag
"""
import time
import numpy as np
#from simple_pid import PID
from state import update_array
from params import WHEEL_DIA, UPRIGHT_THETA, \
        ARDUINO_STEP_MULTIP, RAIL_W, \
        STEPS_PER_REV, GRAVITY_ACCEL, \
        PI, ALPHA, MAX_A, MAX_A_CTRL, \
        MAX_V, MAX_JERK, KAPPA_D_THETA, MAX_V_CTRL
from communication import disable_all, enable_legs, talk

#CTRL_PID = PID(PID_P, PID_I, PID_D, setpoint=UPRIGHT_THETA)

def v_to_cmd_int(vel):
    """
    Get the command integer from velocity.
    """
    rev_per_sec = vel / (WHEEL_DIA * PI)
    steps_per_sec = STEPS_PER_REV * rev_per_sec
    cmd = steps_per_sec / ARDUINO_STEP_MULTIP

    if cmd > 1023:
        print('Warning: reducinf vint, v={}'.format(vel))
        cmd = 1023
    elif cmd < -1024:
        print('Warning: reducinf vint, v={}'.format(vel))
        cmd = -1024

    return int(round(cmd))

def wheels_v_to_cmds(cmd_dict):
    """
    Get the individual wheel cmds from desired v and phidot.
    """
    vel = cmd_dict['v']
    phidot = cmd_dict['phidot'] / 180 * PI

    v_l = vel - phidot * RAIL_W / 2
    v_r = vel + phidot * RAIL_W / 2

    return v_to_cmd_int(v_l), v_to_cmd_int(v_r)

def relocate(ser, run_l):
    """
    Drive the fallen robot back to 0 pos.
    Assumes there are aids to hold the robot roughly upright.
    """
    v = -.05 * np.sign(run_l)
    vcmd = v_to_cmd_int(v)
    cmd = [0, vcmd, vcmd]
    run_time = abs(run_l / v)
    dt = .1
    print('Off by: {:.1f}cm'.format(run_l*100))
    time.sleep(dt)
    enable_legs(ser, 'run')
    print(run_time, dt, run_time//dt)

    for i in range(int(run_time//dt)):
        cmd = [0, vcmd, vcmd]
        talk(ser, {'mode':'run'}, {'cmd':cmd})
        time.sleep(dt)
        print('relocating', cmd, vcmd)
    disable_all(ser, {'mode':'run'})

def get_PID(x, int_x, xdot, P, I, D, dt, kappa_D=None):
    """
    Simple PID, Int term needs to be evaulated outside.
    """
    if kappa_D is not None:
        D = D * np.exp(-kappa_D * np.absolute(x))

    if np.sign(x) == np.sign(int_x):
        int_x += x * dt
    else:
        int_x = x * dt

    return -P*x - int_x*I - xdot*D, int_x

def get_xdd_damp_osc(x, xdot, omega, khi):
    """
    Get the sexond time deriv d^2/dt^2 x for
    damped oscillator given damping param khi, undamped freq omega,
    and current displacement x and its first time deriv xdot.
    """
    return -omega**2*x - 2*khi*omega*xdot

def get_target_theta(state_dict, cmd_dict, ctrl_params_dict):
    """
    Updates the target theta based on current velocity.
    """

    delta_l = state_dict['run_l'][0] - cmd_dict['target_l']
    delta_l_dot = state_dict['v'][0] - cmd_dict['target_v']

    target_a, state_dict['I_pos'] = get_PID(delta_l,
                                            state_dict['I_pos'],
                                            delta_l_dot,
                                            ctrl_params_dict['P_pos'],
                                            ctrl_params_dict['I_pos'],
                                            ctrl_params_dict['D_pos'],
                                            state_dict['dt'])

    target_a = np.clip(target_a, -MAX_A, MAX_A)
    if ((state_dict['v'][0] < -MAX_V) & (delta_l > MAX_A / 2 * 2**2)) or \
       ((state_dict['v'][0] > MAX_V) & (delta_l < - MAX_A / 2 * 2**2)):
        target_a = 0

    cmd_dict['target_a'] = target_a

    tilt_theta = np.arctan(target_a / GRAVITY_ACCEL) / PI * 180

    return UPRIGHT_THETA + tilt_theta

def deg_to_rad(degs):
    return degs / 180 * PI

def get_a_03(state_dict, cmd_dict, ctrl_params_dict):
    """
    Get the reaction a for given state.
    This is based in driving along: Delta theta = exp^(-kappa/t)
    --> thetadot_target = d Delta theta / dt  =  -kappa * Delta theta
    """

    theta = state_dict['theta_predict']
    thetadot = state_dict['thetadot_predict']
    target_theta = cmd_dict['target_theta']
    accel_multip = ctrl_params_dict['accel_mltp']

    delta_theta = theta - target_theta
    delta_thetadot = thetadot

    target_thetadotdot, state_dict['I_theta'] \
            = get_PID(delta_theta,
                      state_dict['I_theta'],
                      delta_thetadot,
                      ctrl_params_dict['P_theta'],
                      ctrl_params_dict['I_theta'],
                      ctrl_params_dict['D_theta'],
                      state_dict['dt'],
                      kappa_D=KAPPA_D_THETA)

    state_dict['target_thetadotdot'] = \
            update_array(state_dict['target_thetadotdot'],
                         target_thetadotdot)
    a1 = GRAVITY_ACCEL * np.tan(deg_to_rad(theta - UPRIGHT_THETA))
    a2 = -(target_thetadotdot / 180 * PI) / (ALPHA * np.cos(deg_to_rad(theta - UPRIGHT_THETA)))

    # used for debugging:
    state_dict['a1'] = update_array(state_dict['a1'], a1)
    state_dict['a2'] = update_array(state_dict['a2'], a2)

    accel = accel_multip * (a1 + a2)
    #accel = accel_multip * (GRAVITY_ACCEL * np.tan(deg_to_rad(theta - UPRIGHT_THETA)) \
    #    - (target_thetadotdot / 180 * PI) / (ALPHA * np.cos(deg_to_rad(theta - UPRIGHT_THETA))))

    dt = state_dict['dt']
    cur_accel = state_dict['a'][0]

    #if (not state_dict['mode'].startswith('simul')) \
    #   and (abs(accel - cur_accel) > MAX_JERK * dt):
    #    print('MAX Jerk triggered: cur_a = {:.2f} --> {:.2f}'.format(cur_accel,
    #                                                                 accel))
    accel = np.clip(accel,
                    cur_accel - MAX_JERK * dt,
                    cur_accel + MAX_JERK * dt)
    return np.clip(accel, -MAX_A_CTRL, MAX_A_CTRL)
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

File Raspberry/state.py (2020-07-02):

import numpy as np
from params import UPRIGHT_THETA, PI
from modelpatric import get_thetadotdot



def check_status(state_dict):

    theta = state_dict['theta_measured'][0]

    if ((theta - UPRIGHT_THETA) < -30) or (30 < (theta-UPRIGHT_THETA)):
        print('FELL: {}'.format(theta-UPRIGHT_THETA))
        for key, val in state_dict.items():
            print(key, val)
        return 'fell'
    else:
        return 'upright'

def update_array(arr, latest_value):

    arr[1:] = arr[:-1]
    arr[0] = latest_value
    return arr

def update_cmd_vars(state_dict, cmd_dict):
    """
    These need t be updated before new command is calculated.
    """
    state_dict['v'] = update_array(state_dict['v'], cmd_dict['v'])
    state_dict['phidot'] = update_array(state_dict['phidot'], cmd_dict['phidot'])

def reset_location(state_dict):

    for key in ['x', 'y', 'phi']:
        state_dict[key] = np.zeros(3)


def update_location(state_dict):
    """
    Update the location according to phidot and v.
    """

    dt = state_dict['times'][0] - state_dict['times'][1]
    dphi = state_dict['phidot'][1] / 180 * PI * dt
    dl = state_dict['v'][1] * dt
    phi = state_dict['phi'][0] / 180 * PI

    # update the turn angle:
    phi_now = phi + dphi
    state_dict['phi'] = update_array(state_dict['phi'], phi_now / PI * 180)

    # Update run length
    l_now = state_dict['run_l'][0] + dl
    state_dict['run_l'] = update_array(state_dict['run_l'], l_now)

    # Update abs run l
    abs_l_now = state_dict['abs_run_l'][0] + abs(dl)
    state_dict['abs_run_l'] = update_array(state_dict['abs_run_l'], abs_l_now)

    # Radius is always positive or None for straight
    turn_radius = np.abs(dl/dphi) if dphi != 0 else None

    # in coordinate system prime, where x is aligned with
    # current heading phi, we have following:
    if turn_radius is None:
        dx_p, dy_p = dl, 0
    else:
        # Note that phidot is defined according to right hand
        # rule where the face of robot is the fingers.
        dx_p = turn_radius * np.sin(dphi) * np.sign(dl)
        dy_p = turn_radius * (1 - np.cos(dphi)) * np.sign(dphi)

    # in primed coords after the turn we have moved:
    dr_p = np.array([dx_p, dy_p]).T

    # the heading is given by the phi - we still need to transform
    # to fixed coord system:
    rotation_matrix = np.array([[np.cos(phi), -np.sin(phi)],
                                [np.sin(phi),  np.cos(phi)]])

    dr = rotation_matrix.dot(dr_p).T
    x = state_dict['x'][0] + dr[0]
    y = state_dict['y'][0] + dr[1]

    state_dict['x'] = update_array(state_dict['x'], x)
    state_dict['y'] = update_array(state_dict['y'], y)


def get_second_deriv(times, values):

    dt1 = times[0] - times[1]
    dt2 = times[1] - times[2]

    return ((values[0] - values[1])/dt1 \
            - (values[1] - values[2])/dt2) / (dt1/2 + dt2/2)

def update_state(state_dict, kl, theta, cur_time):

    times = state_dict['times']
    state_dict['times'] = update_array(times, cur_time)
    state_dict['dt'] = np.diff(times[::-1]).mean()

    # Update measurements
    #===========================================
    state_dict['theta_measured'] = update_array(state_dict['theta_measured'],
                                                theta)
    thetadot_measured = \
            (state_dict['theta_measured'][0] - state_dict['theta_measured'][1]) / \
            (state_dict['times'][0] - state_dict['times'][1])
    state_dict['thetadot_measured'] = \
            update_array(state_dict['thetadot_measured'],
                         thetadot_measured)
    thetadotdot_measured = \
            get_second_deriv(state_dict['times'], state_dict['theta_measured'])
    state_dict['thetadotdot_measured'] = \
            update_array(state_dict['thetadotdot_measured'], thetadotdot_measured)
    state_dict['thetadotdot_measured'][1:] = \
            state_dict['thetadotdot_measured'][:-1]
    #===========================================

    thetadot = (theta - state_dict['theta'][0]) \
        /(state_dict['times'][0] - state_dict['times'][1])

    # Use the klaman to estiamte theta
    if kl is None:
        theta = state_dict['theta_measured'][0]
        thetadot = thetadot_measured
    else:
        theta, thetadot = kl.update(np.array([theta, thetadot]))

    # Update the theta array
    state_dict['theta'] = update_array(state_dict['theta'], theta)
    state_dict['thetadot'] = update_array(state_dict['thetadot'], thetadot)
    state_dict['time_next'] = cur_time + state_dict['dt']

    #for key in ['v', 'phidot']:
    #    # The command is one time step ahead
    #    state_dict[key][1] = cmd_dict[key]


    # update the orientation array:
    #state_dict['thetadot'][2] = state_dict['thetadot'][1]
    state_dict['thetadotdot'][2] = state_dict['thetadotdot'][1]
    state_dict['thetadotdot'][1] = get_second_deriv(state_dict['times'],
                                                    state_dict['theta'])

    update_location(state_dict)

    run_l_arr = state_dict['run_l']
    state_dict['a'][1] = get_second_deriv(times, run_l_arr)

def predict_theta(state_dict, cmd_dict, kl):
    """
    Predict theta using the kalman filter.
    """
    theta = state_dict['theta'][0]
    accel = cmd_dict['a']
    thetadotdot = get_thetadotdot(theta, accel)

    if kl is None:
        state_dict['theta_predict'] = theta
        state_dict['thetadot_predict'] = state_dict['thetadot'][0]
    else:
        state_dict['theta_predict'], state_dict['thetadot_predict'] \
                = kl.predict(control_input=thetadotdot)

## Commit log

2019-10-05 measure change
    [body.scad, design.scad]
2020-01-26 Migrate git root and add arduino and raspberry folders
    [body.scad, build.scad, build.scad.scad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]
2020-02-01 Add stepper and servo control.
2020-02-06 Latest version. Added servo.
2020-02-06 scad updates
    [covers.scad, design.scad, elMount.scad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]
2020-02-06 Moved motor runs under while, read fifo buffer every time only report if serial available.
2020-02-10 With motor enables and limited tune loop
2020-02-10 Motor enable and step mode pins added.
2020-02-11 Better protection against remaining on after crashes etc.
    [communication.py, talk_w_due_devel.py]
2020-03-14 Changed legs to microstepping and increased max speed.
2020-03-17 Balancing with PID
    [batContainer.scad, spring.scad]
2020-03-20 Pid sign change
2020-03-29 Moved PID params to params.py
2020-03-29 Velocities need to be of the earlier time step.
2020-04-01 does not work.. Suggest something better.
    [params.py]
2020-04-20 Separate module for printing and stroing
2020-04-24 state initialization fixed. Also dt in simu bug fixed.
    [balance_run.py, communication.py, control.py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]
2020-04-24 Run params updated prints removed
2020-04-25 test of alternative control. does not work.
    [balance_run.py, control.py, goto.py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]
2020-05-07 Back to pid
2020-05-11 With fixed wheels. New params
    [control.py, params.py]
2020-05-17 Fixing bol added
    [wheel.scad]
2020-05-18 Removed bug from state_dict initialization
    [balance_run.py, communication.py, report.py]
2020-05-24 PID I term zeroed on sign change
2020-05-24 Pid integral term zeroing bug? fix.
    [control.py]
2020-05-24 PID param tuning.
2020-05-26 PID param optim
2020-06-01 Removed jerk print
2020-06-02 If kalman is None give current orientation.
2020-06-02 PID D is now dynamic via param KAPPA_D_THETA
2020-06-05 We now know the maximum possible v available by steppers. That can not be exceeded.
2020-06-05 There is some issue with the accel values. They cannot mach real world...
    [goto.py, params.py]
2020-06-05 Need to make debugging for velocity /accel..
2020-06-06 Collect different terms in accel to figure out what prevents following target theta.
    [balance_run.py, control.py, params.py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]
2020-07-02 More elaborate testing of wheel running.
2020-07-02 Reduced stepper multiplier
2020-07-07 Stepping has some issues - does not take all asked steps.
    [balance_run.py, params.py]
2020-07-14 Weird oscillations but reas
    [balance_run.py, params.py]
2021-09-23 Order of channels fixed
    [balance_run.py]
2021-09-23 No print in mtt
2021-09-23 Hold noise when letting go and should work.
    [params.py]
